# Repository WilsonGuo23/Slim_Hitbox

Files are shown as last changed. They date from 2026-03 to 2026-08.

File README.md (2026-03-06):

# Slim Hitbox Enclosure

This repository contains 3D models, assembly instructions, and detailed documentation for building a compact, 3D-printed hitbox-style arcade controller.

## Project Overview

This Slim Hitbox Enclosure provides a slim, portable alternative to traditional arcade controllers, making it ideal for travel and easy setup. It supports 3D printing, simple assembly, and an ergonomic design. 

> **Note**: Version 1 is exclusively in the southpaw (left-handed) layout. Currently, there is no orthodox (right-handed) version.

## Features

- **Compact and Slim Design**: A low-profile layout optimized for easy handling and storage.
- **3D Printable Components**: Fully printable in standard PLA/ABS materials.
- **Ergonomic Design**: Includes a wrist rest for comfort.
- **Comfortable Assembly**: Chamfered screw holes provide a smoother finish.

## Attributions

This project uses GP2040 to enable the microcontroller to function as a game controller. Special thanks to the knowledgeable members of the GP2040 Discord community for their assistance and expertise, and to the helpful contributors on the r/pcb subreddit for reviewing the board's usability before it was sent for production.

## Prerequisites

- Access to a 3D printer and filament (PLA, ABS, or similar recommended)
- Personal Computer with USB port
- Soldering equipment and basic assembly tools

## Instructions

1. **PCB Manufacturing**: Have the PCB manufactured using the Gerber files in the `fab` folder.
2. **Download STL Files**: Access the STL files from the `models` directory.
3. **Slice and Print**: Use slicing software like Cura or PrusaSlicer to prepare and print the models. Adjust settings as needed based on your specific printer and filament.
4. **Assemble**: Follow the assembly instructions below.

## Parts List

- **Buttons**: 9x 30mm buttons, 3x 24mm buttons
- **Keycaps**: 5x keycaps
- **Panels**: 1x top panel, 1x bottom panel
- **Cables**: 1x Micro USB male to USB male cable ([link](https://www.amazon.com/gp/product/B08BZD66H4/ref=ppx_yo_dt_b_search_asin_title?ie=UTF8&psc=1)) 1x, 1x USB female to USB male cable
  1. (length should match your preferred distance to console or PC)
- **Hardware**: 6x M3 x 20mm screws, 6x M3 bolts
- **Feet**: 6x printed feet
  1. (ensure bolts fit snugly)
- **Electrical Components**:
  - 1x Raspberry Pi Pico
  - 17x MX Cherry or MX Cherry-compatible keyswitches
  - 2 rows of 100-pin male header pins ([link](https://www.amazon.com/dp/B06ZZN8L9S?ref=ppx_yo2ov_dt_b_fed_asin_title))
  - 1x PCB

## Assembly Instructions

1. **Prepare Feet**: Apply a strong bonding agent to the inner walls of each foot, then insert bolts into all six printed feet.
2. **Microcontroller Setup**: Solder male header pins to the Pico microcontroller.
3. **PCB Assembly**: Solder the microcontroller to the PCB using the header pins.
4. **Keyswitch Installation**: Solder all 17 keyswitches onto the PCB.
5. **Cable Guide**: Attach the Micro USB to USB cable to the Pico and guide it through the channels in the top panel.
6. **Enclosure Assembly**: Place the PCB between the top and bottom panels.
7. **Secure Panels**: Screw the panels together and attach them with the feet.
8. **Install Buttons**: Attach all printed buttons, following the image shown below.

   Slim Hitbox Assembled

9. **Attach USB Cable**: Connect the USB female-to-male cable to the exposed USB head.

## Configuration

1. **Download Firmware**: Get the appropriate microcontroller `.uf2` file from the [GP2040 website](https://gp2040-ce.info/downloads/).
2. **Connect and Install Firmware**: Plug the USB cable into a PC, then drag the `.uf2` file into the storage device that appears in the file explorer when the hitbox is connected.
3. **Configuration Setup**: If the default layout is unsatisfactory, use the [web configurator](https://gp2040-ce.info/web-configurator/) to customize the button layout.
4. **Ready to Play**: Boot up your favorite fighting game and enjoy!

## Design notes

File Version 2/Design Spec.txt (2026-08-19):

# Modular Arcade Controller PCBs

## Project Specification

**Version:** 0.1 Draft

---

# 1. Purpose

The Modular Arcade Controller PCBs project is an open-source collection of PCBs designed to simplify the construction of custom arcade controllers. The project divides common controller functions into dedicated, reusable modules that reduce wiring complexity and improve maintainability.

---

# 2. Motivation

Custom arcade controllers often require extensive point-to-point wiring, making assembly, modification, and troubleshooting time-consuming.

This project replaces much of that wiring with standardized PCB modules that can be reused across multiple controller builds.

---

# 3. Scope

This document defines the overall architecture of the Modular Arcade Controller PCBs project.

Detailed electrical, mechanical, and functional requirements for each PCB are defined in their respective specification documents.

---

# 4. Objectives

The project shall:

* Reduce controller assembly time.
* Minimize custom wiring.
* Support modular hardware expansion.
* Be reusable across multiple controller designs.
* Remain compatible with GP2040-CE.
* Be suitable for hobbyist assembly.

---

# 5. System Architecture

The project consists of four primary PCB modules:

* Action Button PCB
* Movement Button PCB
* Administrative Button PCB
* OLED Display PCB

The Action Button PCB serves as the central controller while the remaining modules provide dedicated functionality through standardized interfaces.

---

# 6. Design Principles

All modules should:

* Perform a single primary function.
* Use standardized electrical interfaces.
* Be reusable across controller designs.
* Be easy to manufacture and assemble.
* Maintain compatibility with future project revisions.

---

# 7. Action Button PCB

The Action Button PCB serves as the primary controller for the system.

It hosts a Raspberry Pi Pico running GP2040-CE firmware while interfacing with the controller's primary action buttons. It also provides power and communication interfaces for the remaining modules.

---

# 8. Movement Button PCB

The Movement Button PCB provides directional inputs for the controller.

It interfaces with the Action Button PCB through the project's standardized connector interface.

---

# 9. Administrative Button PCB

The Administrative Button PCB provides non-gameplay controller inputs such as Start, Select, Home/Xbox, and other system buttons supported by GP2040-CE.

It communicates with the Action Button PCB using the project's standardized interface.

---

# 10. OLED Display PCB

The OLED Display PCB provides the controller's user interface.

It supports an OLED display and a rotary encoder used for menu navigation and firmware-supported configuration features.

---

# 11. Module Interfaces

All PCB modules shall connect using standardized electrical interfaces.

Interface specifications, connector pinouts, and communication protocols are defined separately to ensure compatibility between hardware revisions.

---

# 12. Firmware

The system is designed for GP2040-CE running on the Raspberry Pi Pico located on the Action Button PCB.

Additional modules shall integrate using interfaces supported by the firmware whenever practical.

---

# 13. Future Development

Additional PCB modules may be developed to extend the functionality of the controller.

Future modules should follow the architectural principles defined in this specification and maintain compatibility with the existing module interfaces.

PCB Through holes should be 3mm from each side and pushbutton switch centers should be 24mm from the closest side. 
LEDs are to be placed above the switch 11mm from center to center
Resistors that pair with the LED should be placed to the right of the LED with 4mm from through hole to through hole

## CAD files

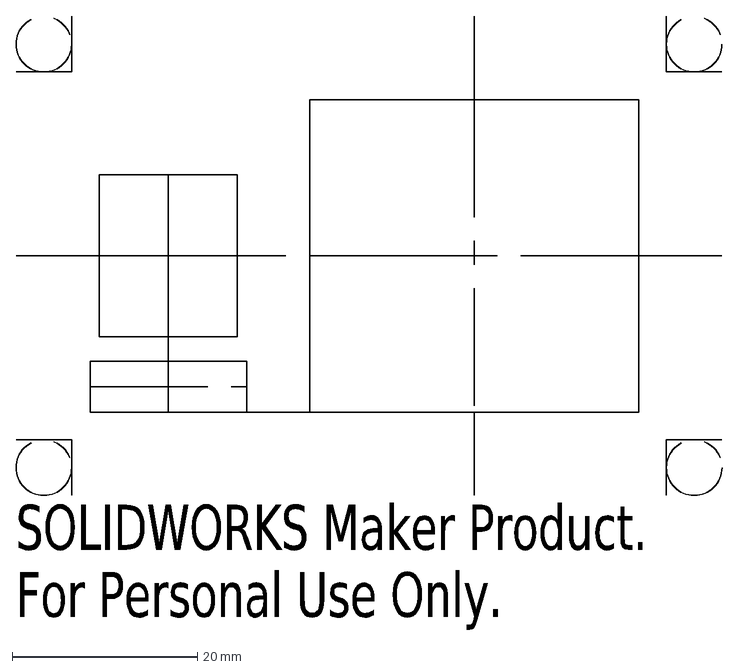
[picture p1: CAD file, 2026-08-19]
Version 2/Solidworks Sketch References/OLED_Display_PCB_User_Sketch_Reference.DXF
SOLIDWORKS Maker Product.
For Personal Use Only.

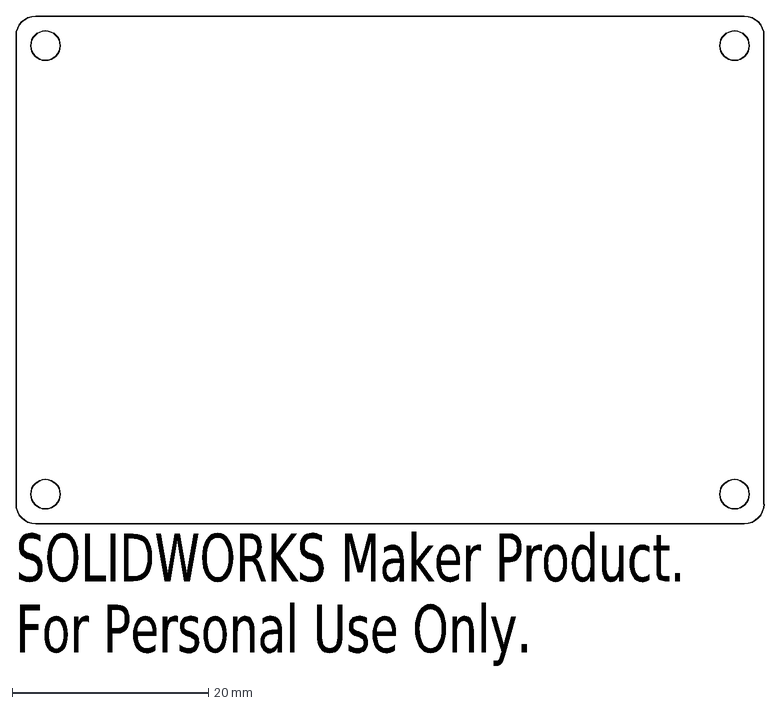
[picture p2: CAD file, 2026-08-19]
Version 2/Solidworks Sketch References/OLED_Display_PCB_Edge_Cuts_Reference.DXF
SOLIDWORKS Maker Product.
For Personal Use Only.

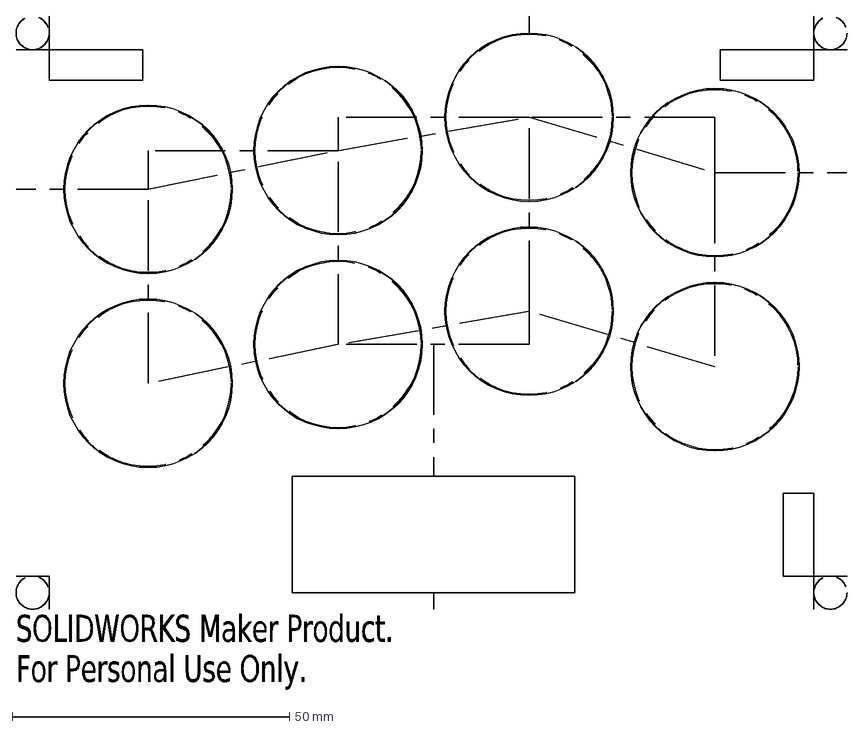
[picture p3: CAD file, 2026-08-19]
Version 2/Solidworks Sketch References/Action_Button_PCB_User_Sketch_Reference.DXF
SOLIDWORKS Maker Product.
For Personal Use Only.

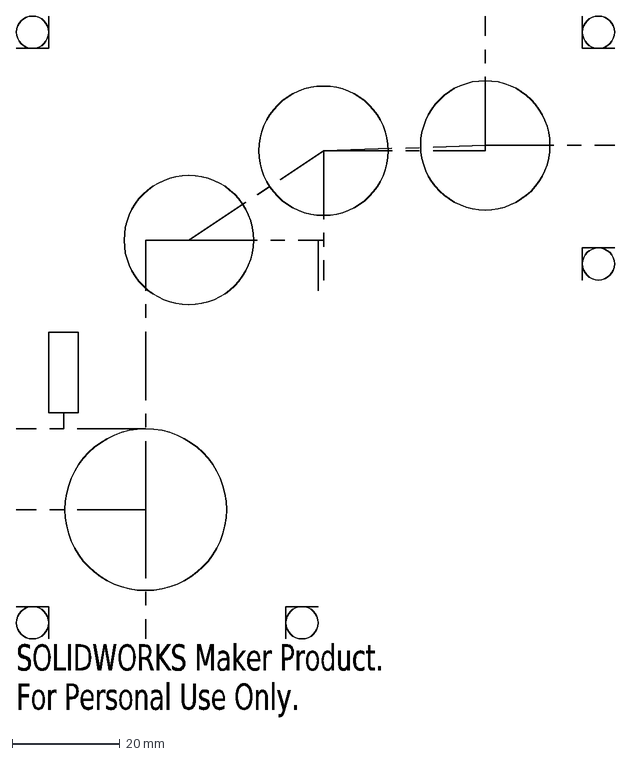
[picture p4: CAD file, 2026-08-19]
Version 2/Solidworks Sketch References/Movement_Button_PCB_User_Sketch_Reference.DXF
SOLIDWORKS Maker Product.
For Personal Use Only.

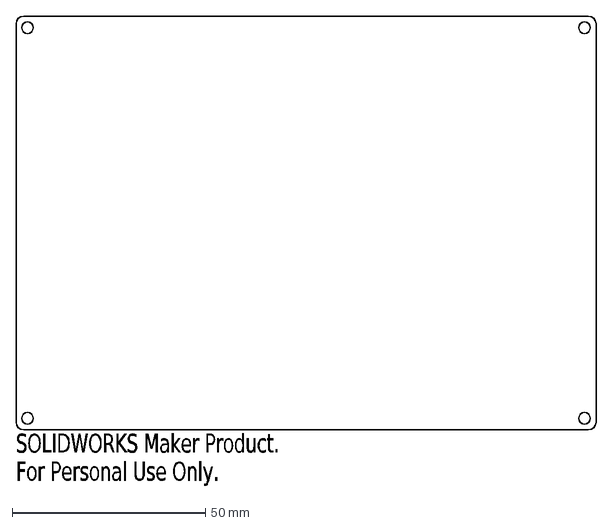
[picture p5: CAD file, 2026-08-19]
Version 2/Solidworks Sketch References/Action_Button_PCB_Edge_Cuts_Reference.DXF
SOLIDWORKS Maker Product.
For Personal Use Only.

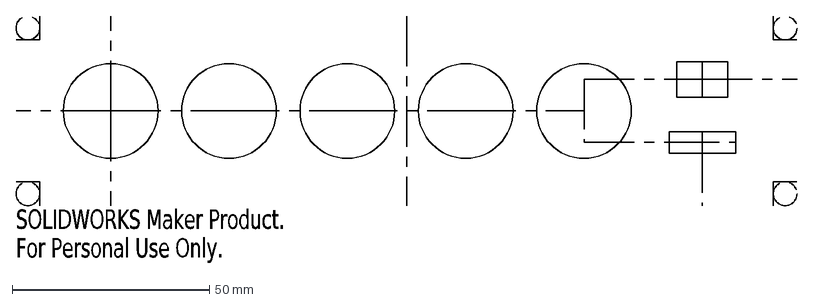
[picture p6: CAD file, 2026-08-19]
Version 2/Solidworks Sketch References/Administrative_PCB_User_Sketch_Reference.DXF
SOLIDWORKS Maker Product.
For Personal Use Only.

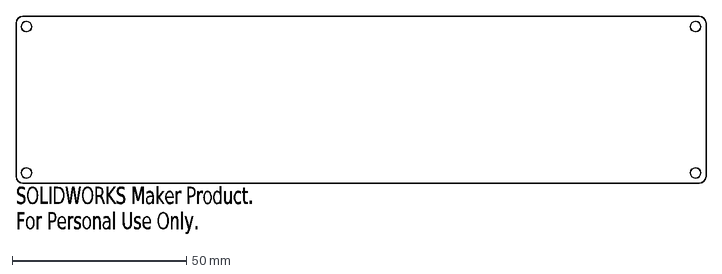
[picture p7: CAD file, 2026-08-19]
Version 2/Solidworks Sketch References/Movement_Button_PCB_Edge_Cuts_Reference.DXF
SOLIDWORKS Maker Product.
For Personal Use Only.

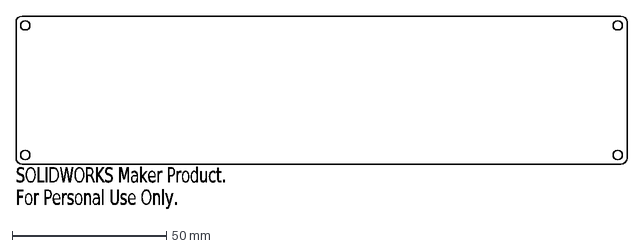
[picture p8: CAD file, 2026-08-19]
Version 2/Solidworks Sketch References/Administrative_PCB_Edge_Cuts_Reference.DXF
SOLIDWORKS Maker Product.
For Personal Use Only.

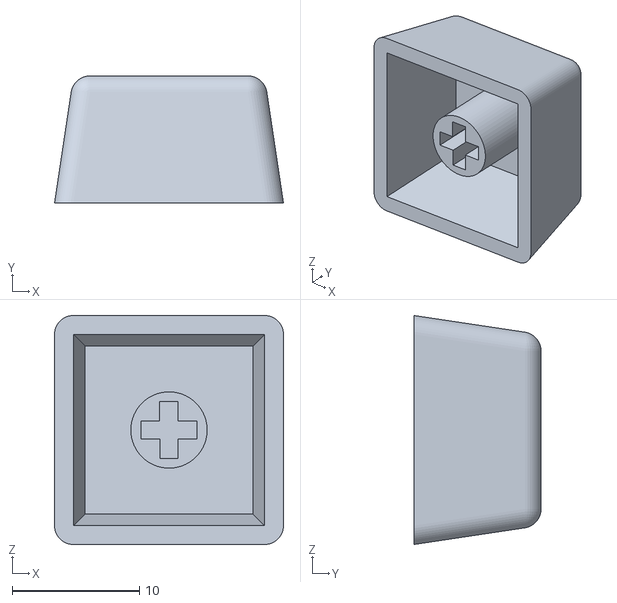
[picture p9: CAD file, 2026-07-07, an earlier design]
Version 1/keycap.stl
18.0 x 10.0 x 18.0

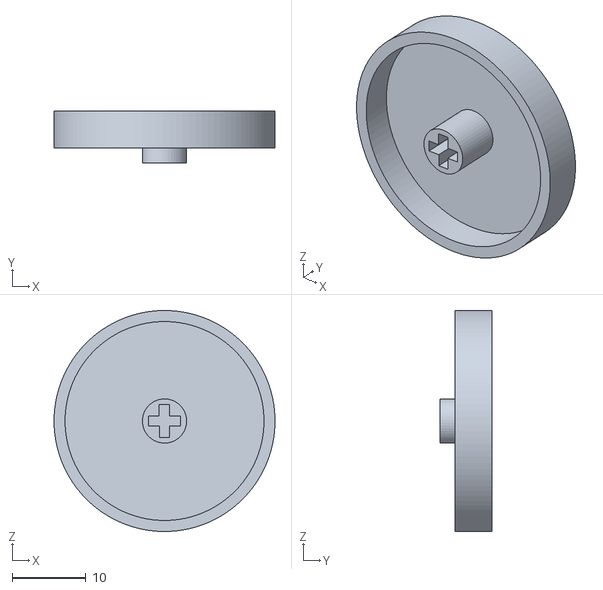
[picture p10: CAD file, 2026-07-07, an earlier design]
Version 1/30mm button.stl
30.0 x 7.00 x 30.0

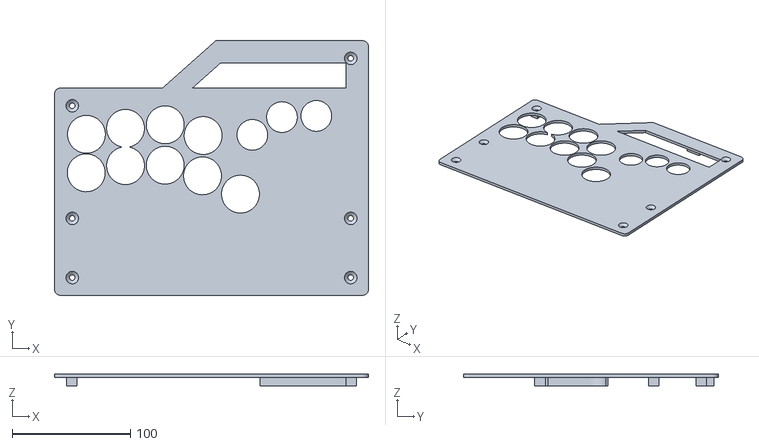
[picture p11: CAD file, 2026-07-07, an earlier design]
Version 1/slim top.stl
265.0 x 215.0 x 10.0

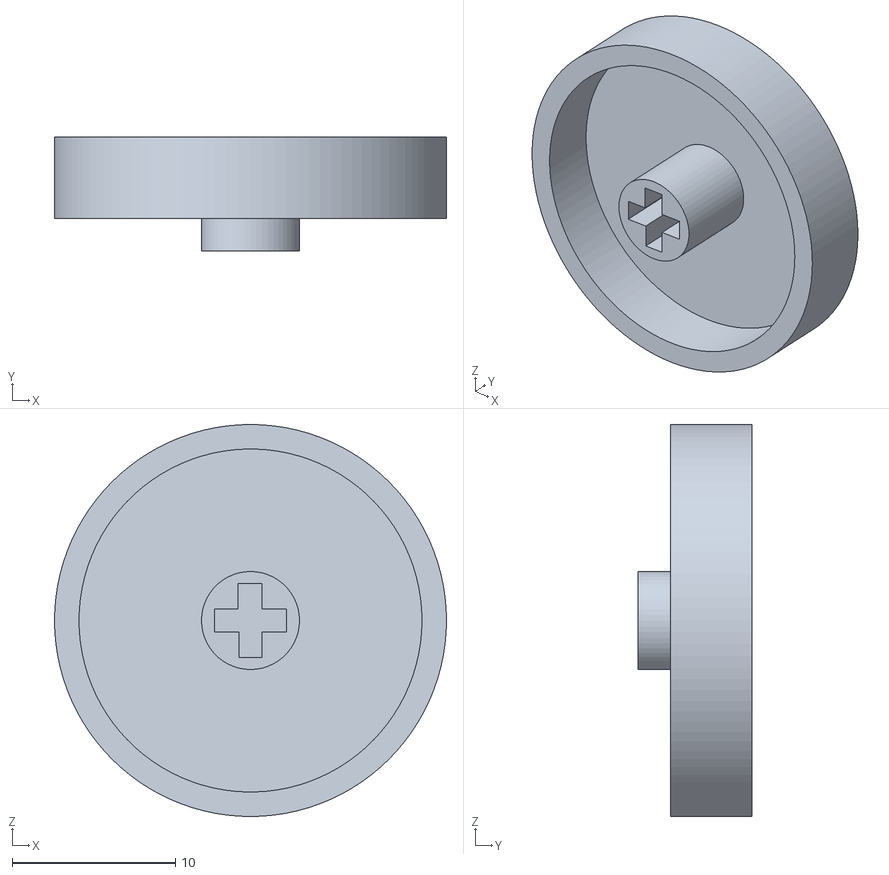
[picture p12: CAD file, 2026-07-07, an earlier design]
Version 1/24mm button.stl
24.0 x 7.00 x 24.0

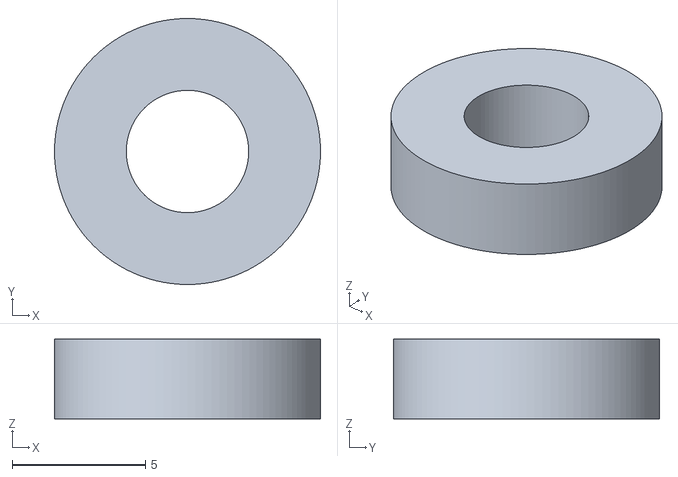
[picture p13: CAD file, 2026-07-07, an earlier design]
Version 1/hole test.stl
10.0 x 10.0 x 3.00

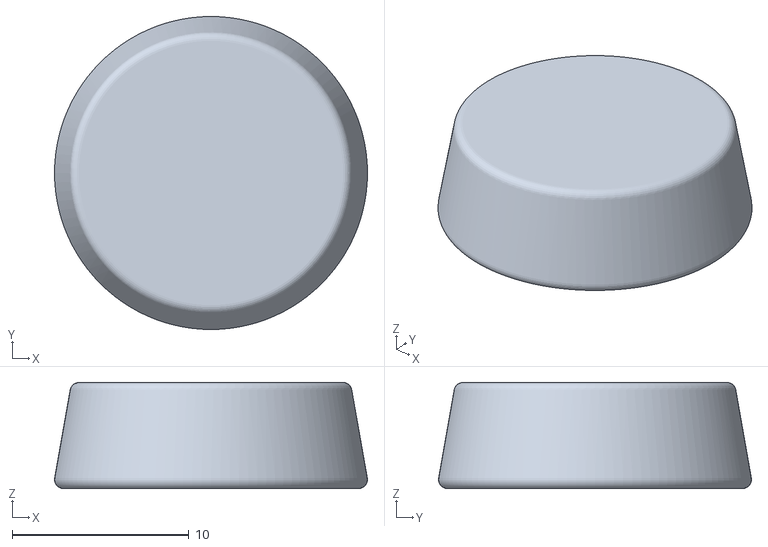
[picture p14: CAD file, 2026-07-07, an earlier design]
Version 1/foot.stl
17.7 x 17.7 x 6.00

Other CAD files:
Version 2/OLED_Display_PCB_Reference.SLDPRT
Version 2/Action_Button_PCB_Reference.SLDPRT
Version 2/Movement_Button_PCB_Reference.SLDPRT
Version 2/Administrative_PCB_Reference.SLDPRT
Version 1/slim_bottom.stl

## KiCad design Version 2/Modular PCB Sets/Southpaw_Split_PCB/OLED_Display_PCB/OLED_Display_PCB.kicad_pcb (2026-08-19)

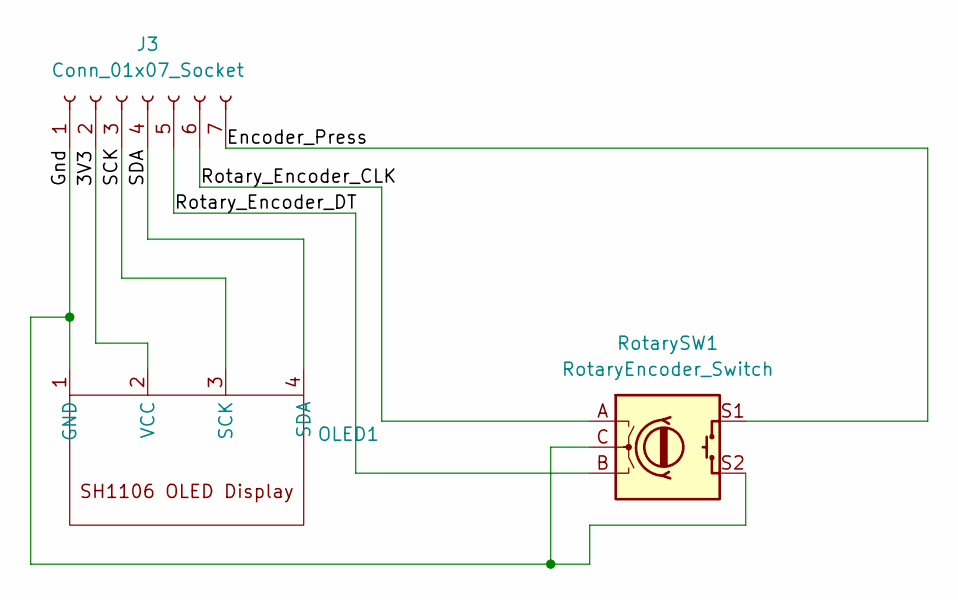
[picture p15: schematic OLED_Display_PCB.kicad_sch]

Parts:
J3: Conn_01x07_Socket; JST_PH_B7B-PH-K_1x07_P2.00mm_Vertical
OLED1: Hosyond SH1106 OLED Display
RotarySW1: RotaryEncoder_Switch; RotaryEncoder_Alps_EC11E-Switch_Vertical_H20mm

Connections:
/3V3: J3.2, OLED1.2 (VCC)
/Encoder_Press: J3.7, RotarySW1.S1
/Gnd: J3.1, OLED1.1 (GND), RotarySW1.C, RotarySW1.S2
/Rotary_Encoder_CLK: J3.6, RotarySW1.A
/Rotary_Encoder_DT: J3.5, RotarySW1.B
/SCK: J3.3, OLED1.3 (SCK)
/SDA: J3.4, OLED1.4 (SDA)

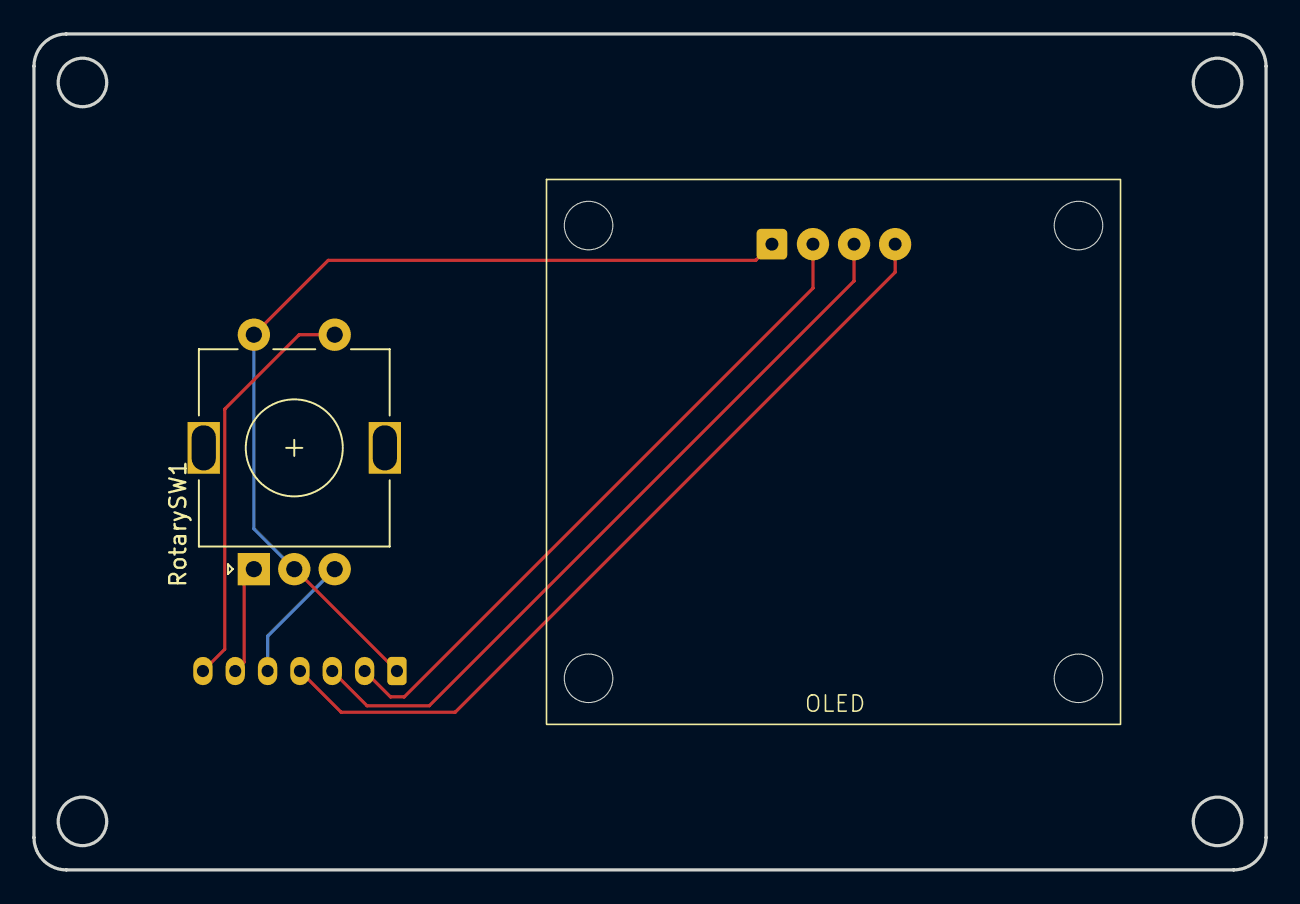
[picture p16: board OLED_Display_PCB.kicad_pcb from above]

Board: 2 copper layers, 76.2 x 51.7 mm, 3 parts (1 on the bottom side), 7 nets.

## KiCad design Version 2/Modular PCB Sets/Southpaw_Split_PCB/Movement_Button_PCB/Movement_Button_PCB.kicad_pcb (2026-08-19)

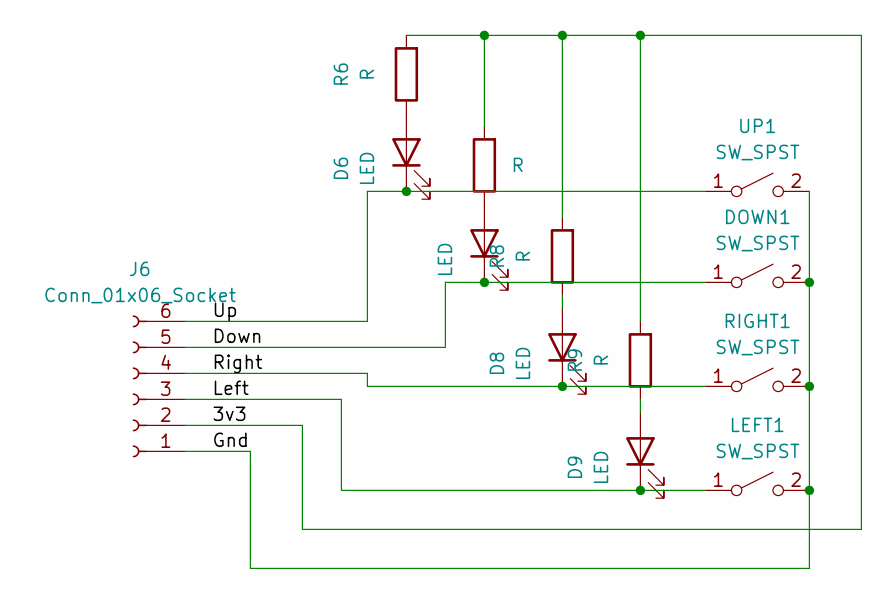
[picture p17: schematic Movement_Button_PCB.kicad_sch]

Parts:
D6, D7, D8, D9: LED; LED_D5.0mm
DOWN1: SW_SPST; SW_Cherry_MX_1.00u_PCB
J6: Conn_01x06_Socket; JST_PH_B6B-PH-K_1x06_P2.00mm_Vertical
LEFT1: SW_SPST; SW_Cherry_MX_1.00u_PCB
R6, R7, R8, R9: R; R_Axial_DIN0207_L6.3mm_D2.5mm_P10.16mm_Horizontal
RIGHT1: SW_SPST; SW_Cherry_MX_1.00u_PCB
UP1: SW_SPST; SW_Cherry_MX_1.00u_PCB

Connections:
/3v3: J6.2, R6.2, R7.2, R8.2, R9.2
/Down: D7.1 (K), DOWN1.1 (A), J6.5
/Gnd: DOWN1.2 (B), J6.1, LEFT1.2 (B), RIGHT1.2 (B), UP1.2 (B)
/Left: D9.1 (K), J6.3, LEFT1.1 (A)
/Right: D8.1 (K), J6.4, RIGHT1.1 (A)
/Up: D6.1 (K), J6.6, UP1.1 (A)
unnamed: D6.2 (A), R6.1
unnamed: D7.2 (A), R7.1
unnamed: D8.2 (A), R8.1
unnamed: D9.2 (A), R9.1

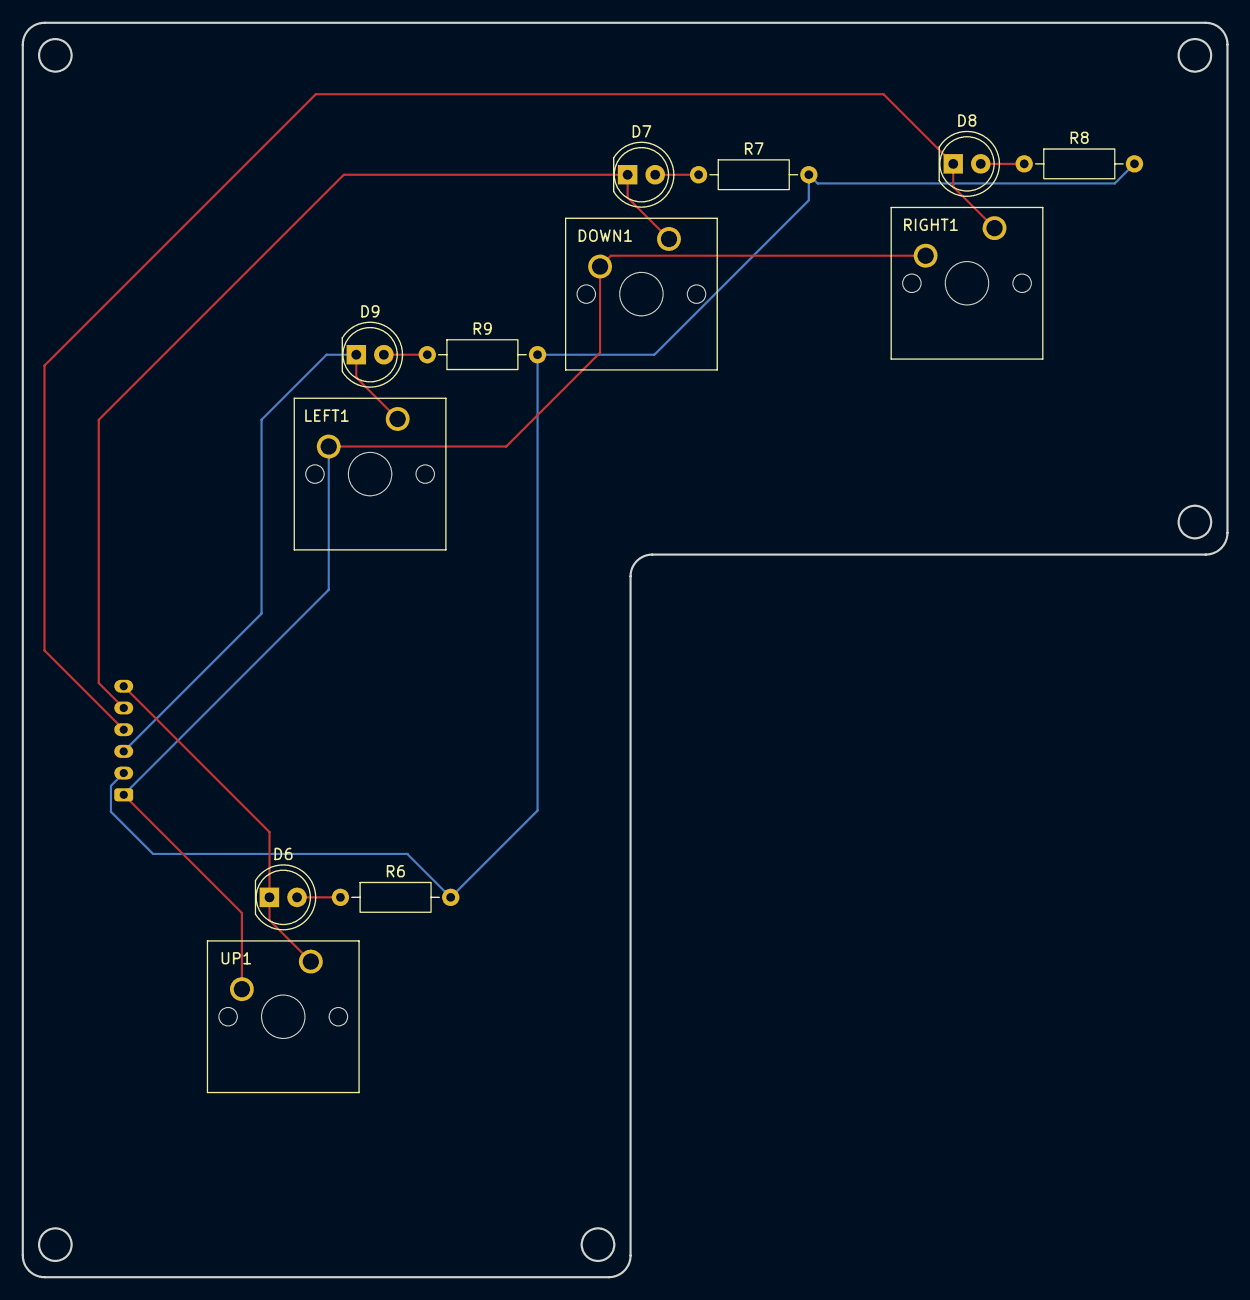
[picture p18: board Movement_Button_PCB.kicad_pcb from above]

Board: 2 copper layers, 111.0 x 115.6 mm, 13 parts (1 on the bottom side), 10 nets.

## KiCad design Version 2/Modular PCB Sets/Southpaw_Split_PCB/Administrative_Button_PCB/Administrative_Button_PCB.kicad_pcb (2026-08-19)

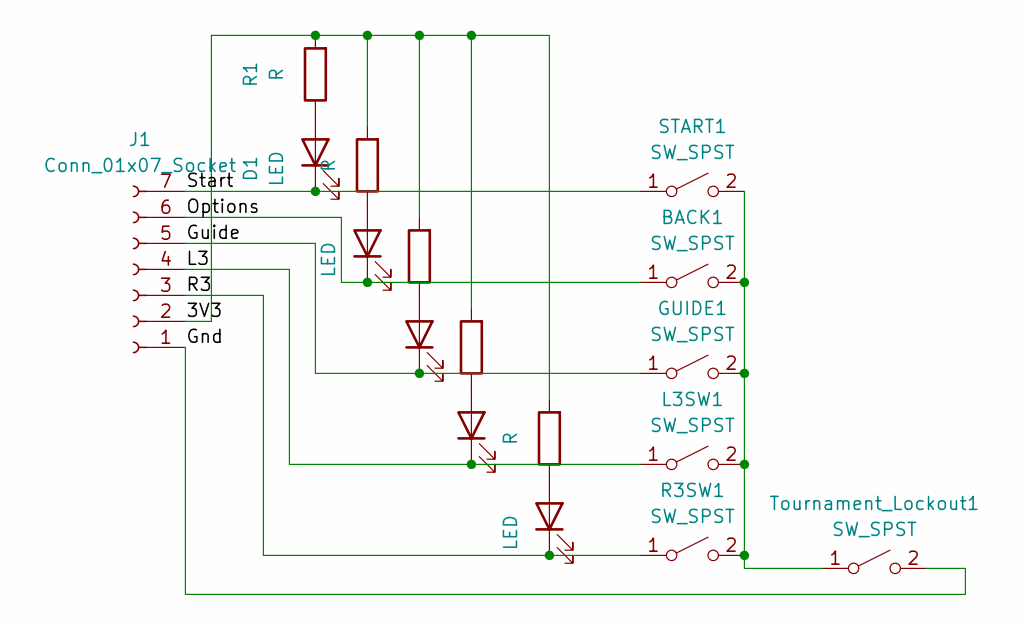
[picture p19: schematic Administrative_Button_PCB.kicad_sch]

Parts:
BACK1: SW_SPST; SW_Cherry_MX_1.00u_PCB
D1, D2, D3, D4, D5: LED; LED_D5.0mm
GUIDE1: SW_SPST; SW_Cherry_MX_1.00u_PCB
J1: Conn_01x07_Socket; JST_PH_B7B-PH-K_1x07_P2.00mm_Vertical
L3SW1: SW_SPST; SW_Cherry_MX_1.00u_PCB
R1, R2, R3, R4, R5: R; R_Axial_DIN0207_L6.3mm_D2.5mm_P10.16mm_Horizontal
R3SW1: SW_SPST; SW_Cherry_MX_1.00u_PCB
START1: SW_SPST; SW_Cherry_MX_1.00u_PCB
Tournament_Lockout1: SW_SPST; MTS-101 Toggle Switch

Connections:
/3V3: J1.2, R1.2, R2.2, R3.2, R4.2, R5.2
/Gnd: J1.1, Tournament_Lockout1.2 (B)
/Guide: D3.1 (K), GUIDE1.1 (A), J1.5
/L3: D4.1 (K), J1.4, L3SW1.1 (A)
/Options: BACK1.1 (A), D2.1 (K), J1.6
/R3: D5.1 (K), J1.3, R3SW1.1 (A)
/Start: D1.1 (K), J1.7, START1.1 (A)
unnamed: BACK1.2 (B), GUIDE1.2 (B), L3SW1.2 (B), R3SW1.2 (B), START1.2 (B), Tournament_Lockout1.1 (A)
unnamed: D1.2 (A), R1.1
unnamed: D2.2 (A), R2.1
unnamed: D3.2 (A), R3.1
unnamed: D4.2 (A), R4.1
unnamed: D5.2 (A), R5.1

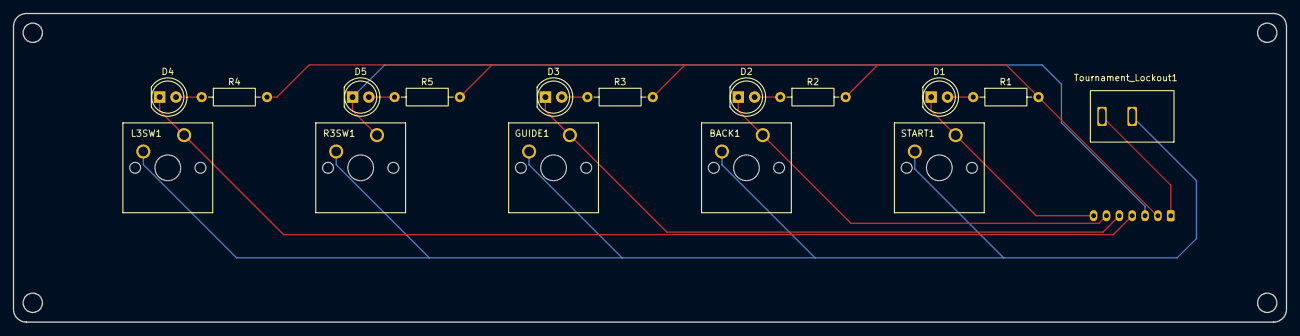
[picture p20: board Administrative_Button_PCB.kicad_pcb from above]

Board: 2 copper layers, 198.0 x 48.0 mm, 17 parts (1 on the bottom side), 13 nets.

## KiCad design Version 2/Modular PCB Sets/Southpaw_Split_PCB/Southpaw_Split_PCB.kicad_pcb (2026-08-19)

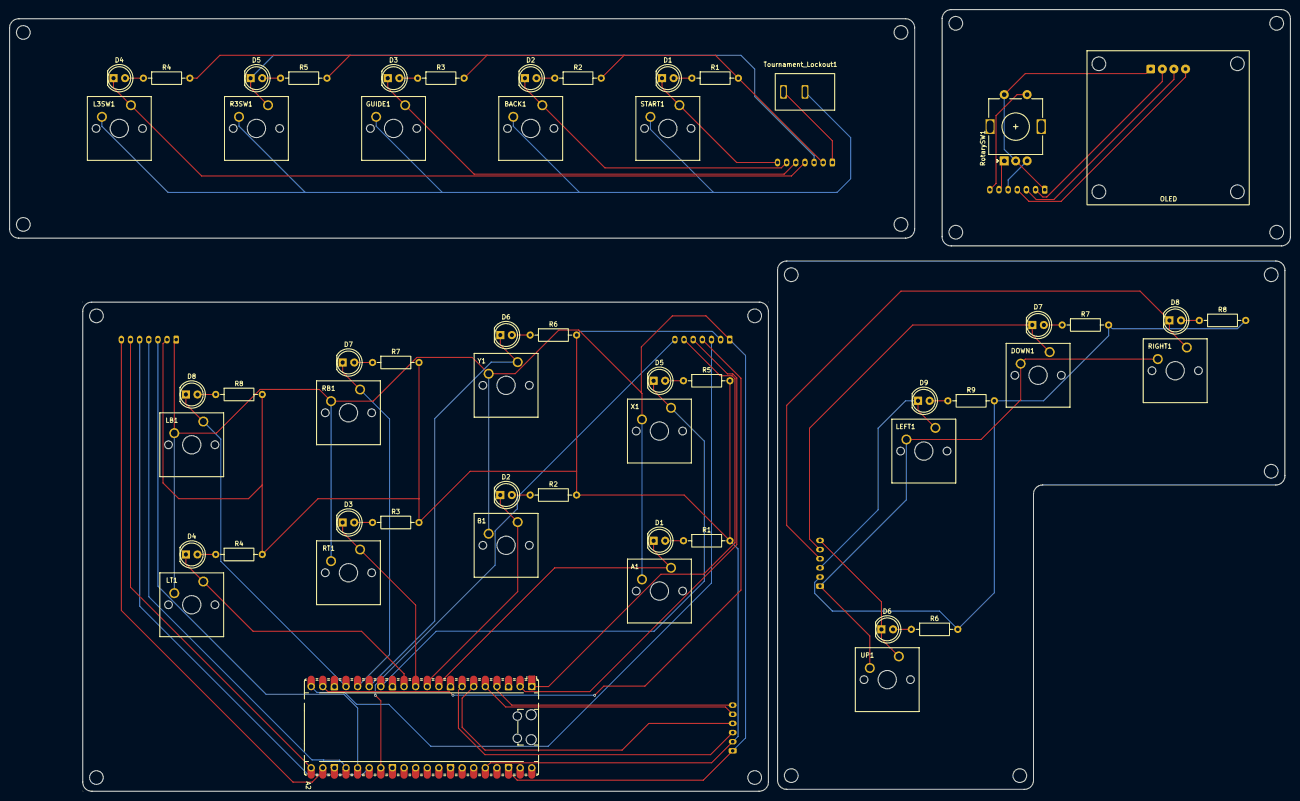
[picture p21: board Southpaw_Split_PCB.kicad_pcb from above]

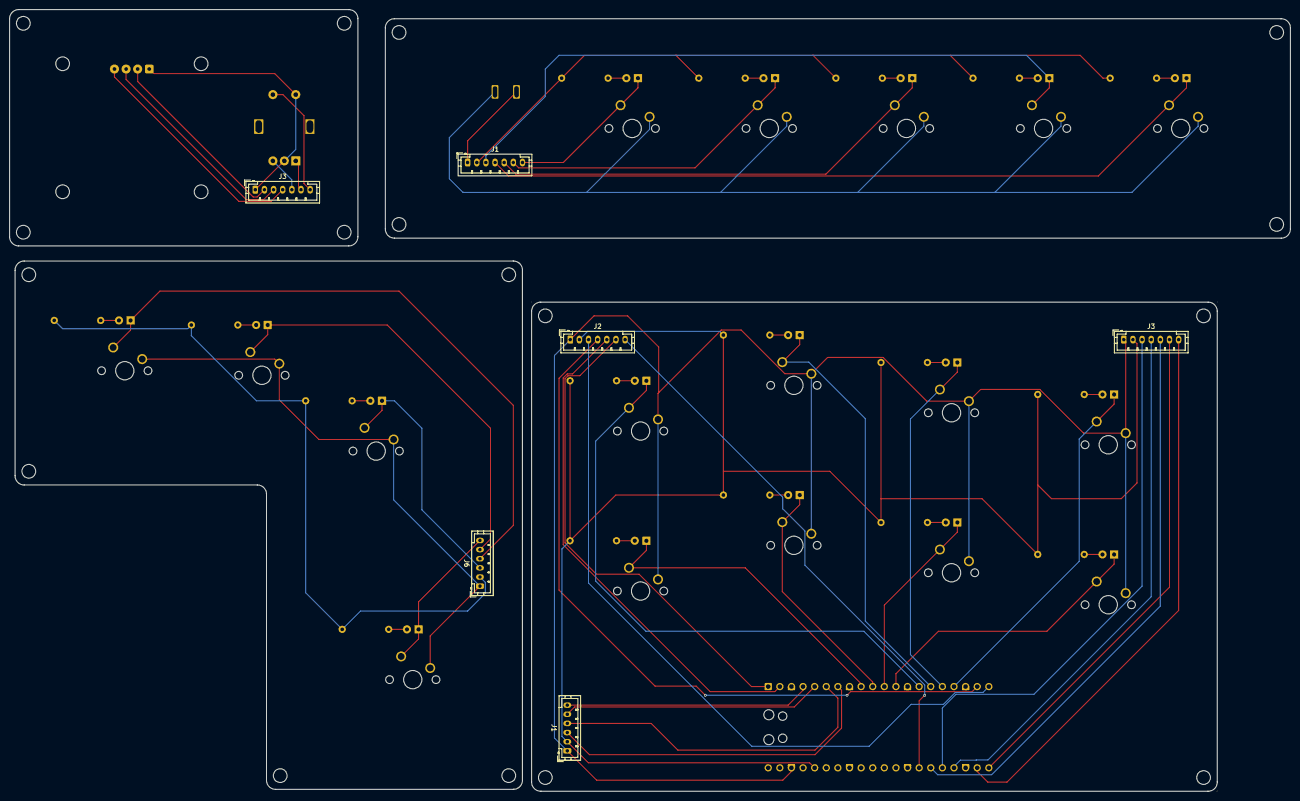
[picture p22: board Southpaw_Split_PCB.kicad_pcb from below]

Board: 2 copper layers, 280.2 x 171.0 mm, 61 parts (6 on the bottom side), 37 nets.

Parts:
A1: SW_SPST; SW_Cherry_MX_1.00u_PCB
A2: RaspberryPi_Pico; RaspberryPi_Pico_Common_Unspecified
B1: SW_SPST; SW_Cherry_MX_1.00u_PCB
BACK1: SW_SPST; SW_Cherry_MX_1.00u_PCB
D1, D1#2, D2, D2#2, D3, D3#2, D4, D4#2, D5, D5#2, D6, D6#2, D7, D7#2, D8, D8#2, D9: LED; LED_D5.0mm
DOWN1: SW_SPST; SW_Cherry_MX_1.00u_PCB
GUIDE1: SW_SPST; SW_Cherry_MX_1.00u_PCB
J1, J6: Conn_01x06_Socket; JST_PH_B6B-PH-K_1x06_P2.00mm_Vertical
J1#2, J2, J3, J3#2: Conn_01x07_Socket; JST_PH_B7B-PH-K_1x07_P2.00mm_Vertical
L3SW1: SW_SPST; SW_Cherry_MX_1.00u_PCB
LB1: SW_SPST; SW_Cherry_MX_1.00u_PCB
LEFT1: SW_SPST; SW_Cherry_MX_1.00u_PCB
LT1: SW_SPST; SW_Cherry_MX_1.00u_PCB
OLED1: Hosyond SH1106 OLED Display
R1, R1#2, R2, R2#2, R3, R3#2, R4, R4#2, R5, R5#2, R6, R6#2, R7, R7#2, R8, R8#2, R9: R; R_Axial_DIN0207_L6.3mm_D2.5mm_P10.16mm_Horizontal
R3SW1: SW_SPST; SW_Cherry_MX_1.00u_PCB
RB1: SW_SPST; SW_Cherry_MX_1.00u_PCB
RIGHT1: SW_SPST; SW_Cherry_MX_1.00u_PCB
RT1: SW_SPST; SW_Cherry_MX_1.00u_PCB
RotarySW1: RotaryEncoder_Switch; RotaryEncoder_Alps_EC11E-Switch_Vertical_H20mm
START1: SW_SPST; SW_Cherry_MX_1.00u_PCB
Tournament_Lockout1: SW_SPST; MTS-101 Toggle Switch
UP1: SW_SPST; SW_Cherry_MX_1.00u_PCB
X1: SW_SPST; SW_Cherry_MX_1.00u_PCB
Y1: SW_SPST; SW_Cherry_MX_1.00u_PCB

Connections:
3v3: A2.36 (3V3), J1.2, J2.2, J3#2.2, R1.2, R2#2.2, R3#2.2, R4.2, R5.2, R6#2.2, R7.2, R8.2
/3V3: J1#2.2, J3.2, OLED1.2 (VCC), R1#2.2, R2.2, R3.2, R4#2.2, R5#2.2
/3v3: J6.2, R6.2, R7#2.2, R8#2.2, R9.2
/Down: A2.5 (GPIO3), D7.1 (K), DOWN1.1 (A), J1.5, J6.5
/Encoder_Press: A2.27 (GPIO21), J2.7, J3.7, RotarySW1.S1
/Gnd: DOWN1.2 (B), J1#2.1, J3.1, J6.1, LEFT1.2 (B), OLED1.1 (GND), RIGHT1.2 (B), RotarySW1.C, RotarySW1.S2, Tournament_Lockout1.2 (B), UP1.2 (B)
/Guide: A2.26 (GPIO20), D3#2.1 (K), GUIDE1.1 (A), J1#2.5, J3#2.5
/L3: A2.24 (GPIO18), D4#2.1 (K), J1#2.4, J3#2.4, L3SW1.1 (A)
/Left: A2.7 (GPIO5), D9.1 (K), J1.3, J6.3, LEFT1.1 (A)
/Options: A2.21 (GPIO16), BACK1.1 (A), D2#2.1 (K), J1#2.6, J3#2.6
/R3: A2.25 (GPIO19), D5#2.1 (K), J1#2.3, J3#2.3, R3SW1.1 (A)
/Right: A2.6 (GPIO4), D8.1 (K), J1.4, J6.4, RIGHT1.1 (A)
/Rotary_Encoder_CLK: A2.1 (GPIO0), J2.6, J3.6, RotarySW1.A
/Rotary_Encoder_DT: A2.2 (GPIO1), J2.5, J3.5, RotarySW1.B
/SCK: A2.20 (GPIO15), J2.3, J3.3, OLED1.3 (SCK)
/SDA: A2.19 (GPIO14), J2.4, J3.4, OLED1.4 (SDA)
/Start: A2.22 (GPIO17), D1.1 (K), J1#2.7, J3#2.7, START1.1 (A)
/Up: A2.4 (GPIO2), D6.1 (K), J1.6, J6.6, UP1.1 (A)
A: A1.1 (A), A2.9 (GPIO6), D1#2.1 (K)
B: A2.10 (GPIO7), B1.1 (A), D2.1 (K)
GND: A1.2 (B), A2.3 (GND), A2.8 (GND), A2.13 (GND), A2.18 (GND), A2.23 (GND), A2.28 (GND), A2.38 (GND), B1.2 (B), J1.1, J2.1, J3#2.1, LB1.2 (B), LT1.2 (B), RB1.2 (B), RT1.2 (B), X1.2 (B), Y1.2 (B)
LB: A2.17 (GPIO13), D8#2.1 (K), LB1.1 (A)
LT: A2.12 (GPIO9), D4.1 (K), LT1.1 (A)
unnamed: BACK1.2 (B), GUIDE1.2 (B), L3SW1.2 (B), R3SW1.2 (B), START1.2 (B), Tournament_Lockout1.1 (A)
unnamed: D1.2 (A), D1#2.2 (A), R1.1, R1#2.1
unnamed: D2.2 (A), D2#2.2 (A), R2.1, R2#2.1
unnamed: D3.2 (A), D3#2.2 (A), R3.1, R3#2.1
unnamed: D4.2 (A), D4#2.2 (A), R4.1, R4#2.1
unnamed: D5.2 (A), D5#2.2 (A), R5.1, R5#2.1
unnamed: D6.2 (A), D6#2.2 (A), R6.1, R6#2.1
unnamed: D7.2 (A), D7#2.2 (A), R7.1, R7#2.1
unnamed: D8.2 (A), D8#2.2 (A), R8.1, R8#2.1
unnamed: D9.2 (A), R9.1
RB: A2.16 (GPIO12), D7#2.1 (K), RB1.1 (A)
RT: A2.11 (GPIO8), D3.1 (K), RT1.1 (A)
X: A2.14 (GPIO10), D5.1 (K), X1.1 (A)
Y: A2.15 (GPIO11), D6#2.1 (K), Y1.1 (A)

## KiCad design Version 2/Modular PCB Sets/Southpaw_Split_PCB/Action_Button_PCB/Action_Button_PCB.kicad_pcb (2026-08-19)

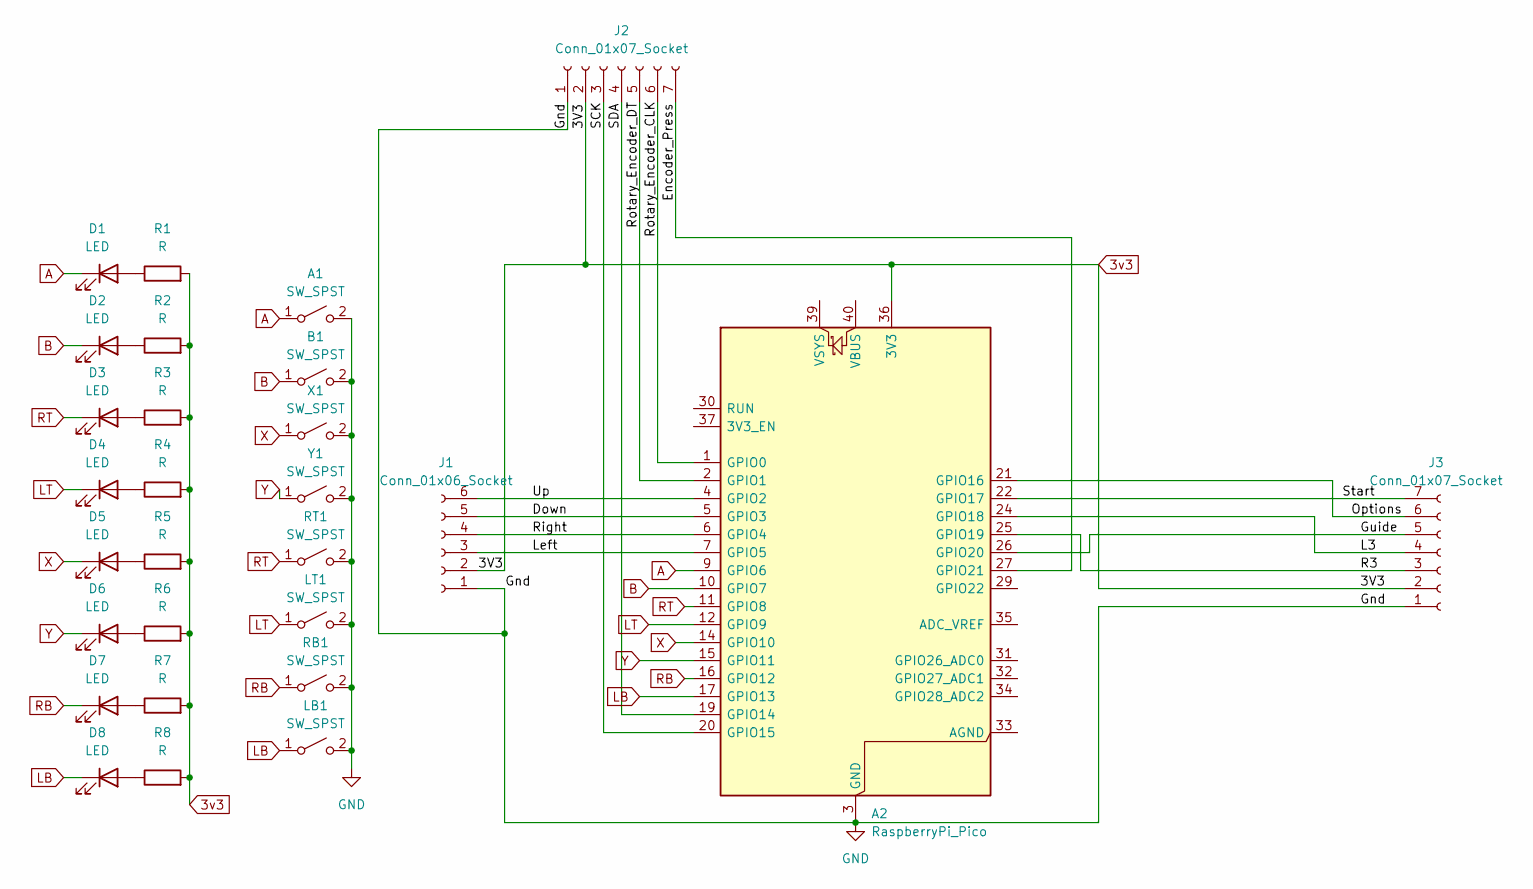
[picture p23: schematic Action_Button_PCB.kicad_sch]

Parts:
A1: SW_SPST; SW_Cherry_MX_1.00u_PCB
A2: RaspberryPi_Pico; RaspberryPi_Pico_Common_Unspecified
B1: SW_SPST; SW_Cherry_MX_1.00u_PCB
D1, D2, D3, D4, D5, D6, D7, D8: LED; LED_D5.0mm
J1: Conn_01x06_Socket; JST_PH_B6B-PH-K_1x06_P2.00mm_Vertical
J2, J3: Conn_01x07_Socket; JST_PH_B7B-PH-K_1x07_P2.00mm_Vertical
LB1: SW_SPST; SW_Cherry_MX_1.00u_PCB
LT1: SW_SPST; SW_Cherry_MX_1.00u_PCB
R1, R2, R3, R4, R5, R6, R7, R8: R; R_Axial_DIN0207_L6.3mm_D2.5mm_P10.16mm_Horizontal
RB1: SW_SPST; SW_Cherry_MX_1.00u_PCB
RT1: SW_SPST; SW_Cherry_MX_1.00u_PCB
X1: SW_SPST; SW_Cherry_MX_1.00u_PCB
Y1: SW_SPST; SW_Cherry_MX_1.00u_PCB

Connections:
3v3: A2.36 (3V3), J1.2, J2.2, J3.2, R1.2, R2.2, R3.2, R4.2, R5.2, R6.2, R7.2, R8.2
/Down: A2.5 (GPIO3), J1.5
/Encoder_Press: A2.27 (GPIO21), J2.7
/Guide: A2.26 (GPIO20), J3.5
/L3: A2.24 (GPIO18), J3.4
/Left: A2.7 (GPIO5), J1.3
/Options: A2.21 (GPIO16), J3.6
/R3: A2.25 (GPIO19), J3.3
/Right: A2.6 (GPIO4), J1.4
/Rotary_Encoder_CLK: A2.1 (GPIO0), J2.6
/Rotary_Encoder_DT: A2.2 (GPIO1), J2.5
/SCK: A2.20 (GPIO15), J2.3
/SDA: A2.19 (GPIO14), J2.4
/Start: A2.22 (GPIO17), J3.7
/Up: A2.4 (GPIO2), J1.6
A: A1.1 (A), A2.9 (GPIO6), D1.1 (K)
B: A2.10 (GPIO7), B1.1 (A), D2.1 (K)
GND: A1.2 (B), A2.3 (GND), A2.8 (GND), A2.13 (GND), A2.18 (GND), A2.23 (GND), A2.28 (GND), A2.38 (GND), B1.2 (B), J1.1, J2.1, J3.1, LB1.2 (B), LT1.2 (B), RB1.2 (B), RT1.2 (B), X1.2 (B), Y1.2 (B)
LB: A2.17 (GPIO13), D8.1 (K), LB1.1 (A)
LT: A2.12 (GPIO9), D4.1 (K), LT1.1 (A)
unnamed: D1.2 (A), R1.1
unnamed: D2.2 (A), R2.1
unnamed: D3.2 (A), R3.1
unnamed: D4.2 (A), R4.1
unnamed: D5.2 (A), R5.1
unnamed: D6.2 (A), R6.1
unnamed: D7.2 (A), R7.1
unnamed: D8.2 (A), R8.1
RB: A2.16 (GPIO12), D7.1 (K), RB1.1 (A)
RT: A2.11 (GPIO8), D3.1 (K), RT1.1 (A)
X: A2.14 (GPIO10), D5.1 (K), X1.1 (A)
Y: A2.15 (GPIO11), D6.1 (K), Y1.1 (A)

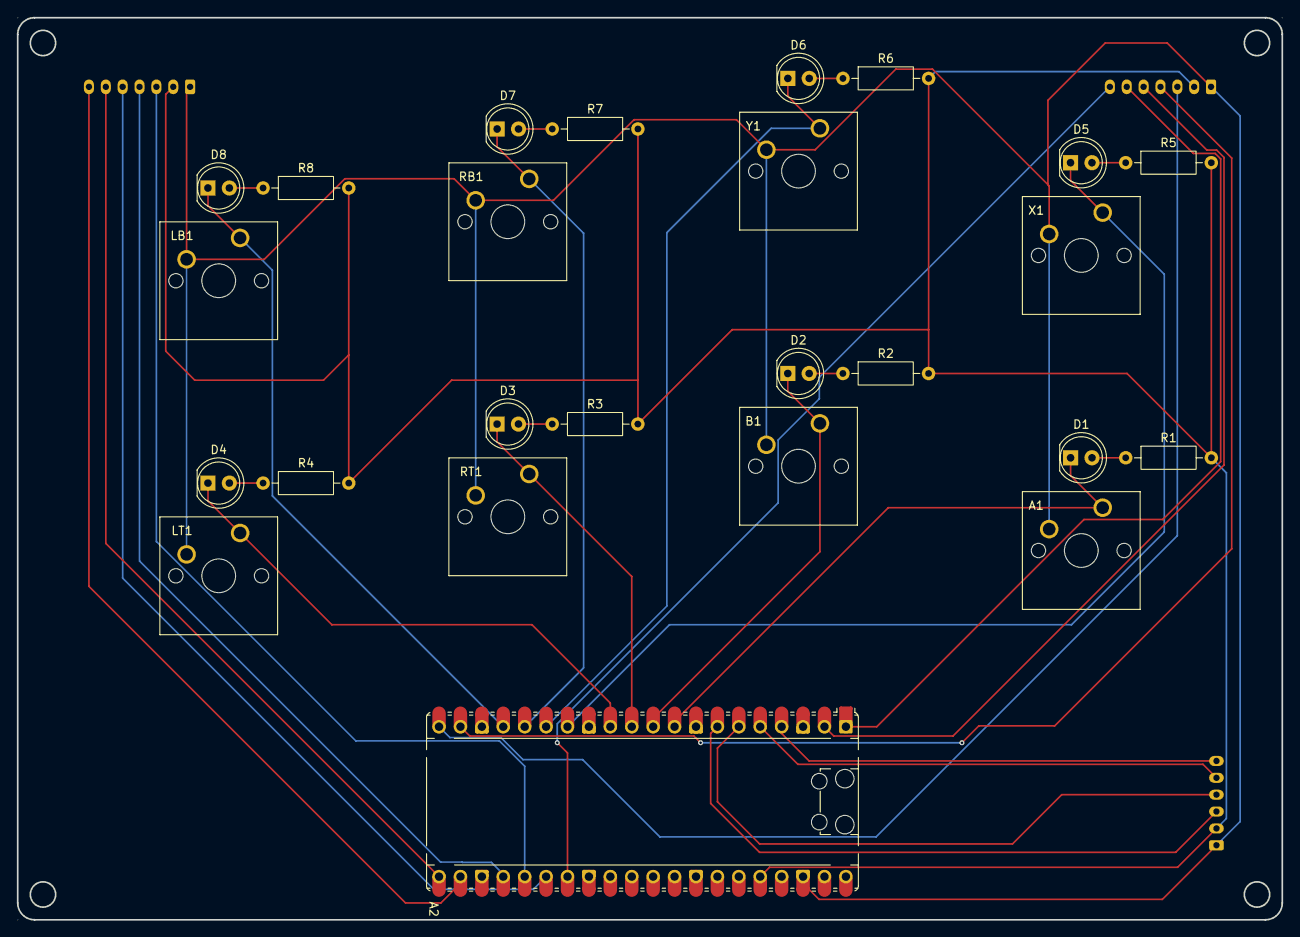
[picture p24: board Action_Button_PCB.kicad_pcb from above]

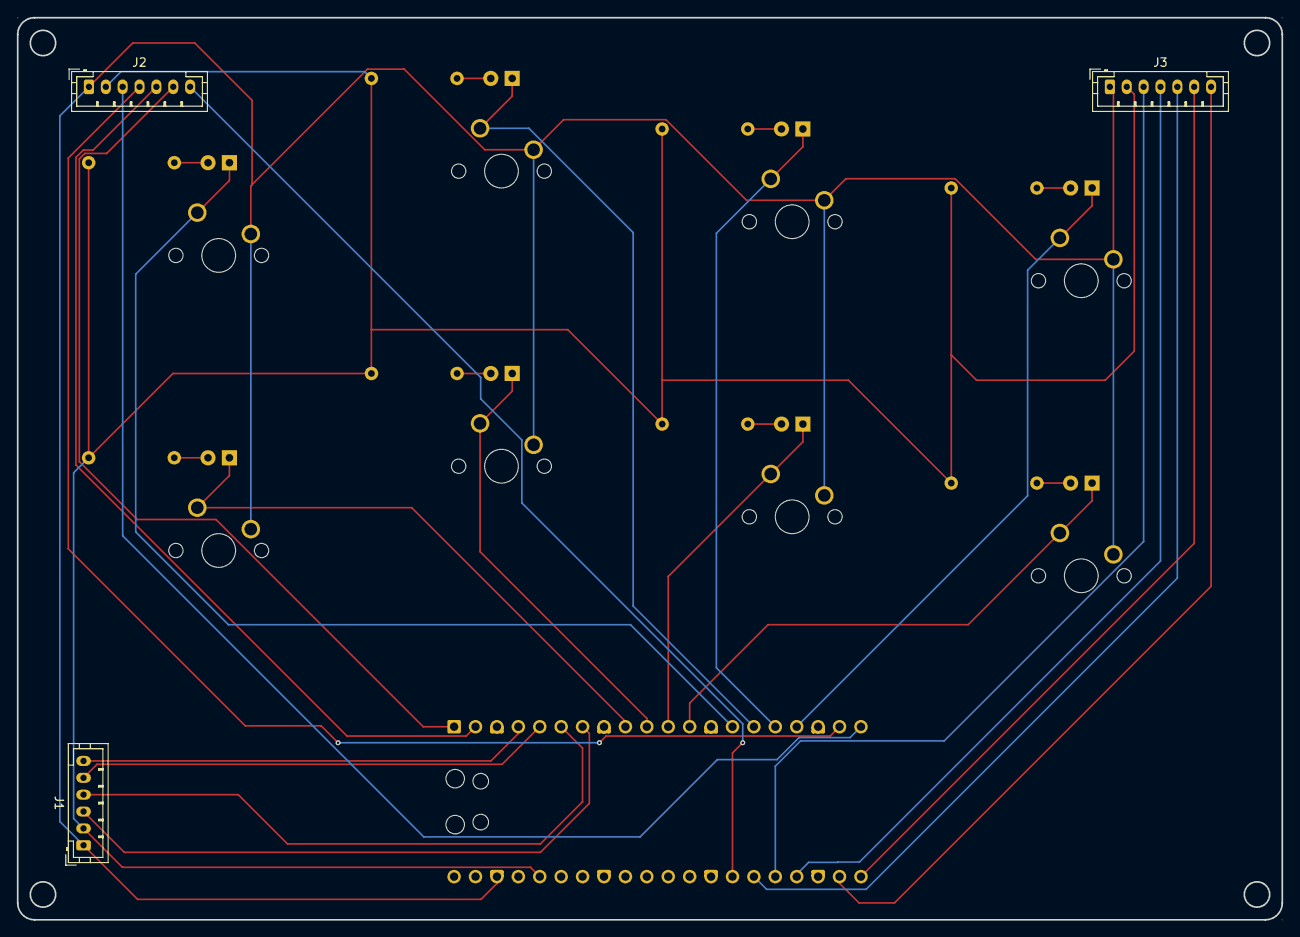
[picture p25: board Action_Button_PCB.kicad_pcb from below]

Board: 2 copper layers, 150.0 x 107.0 mm, 28 parts (3 on the bottom side), 32 nets.

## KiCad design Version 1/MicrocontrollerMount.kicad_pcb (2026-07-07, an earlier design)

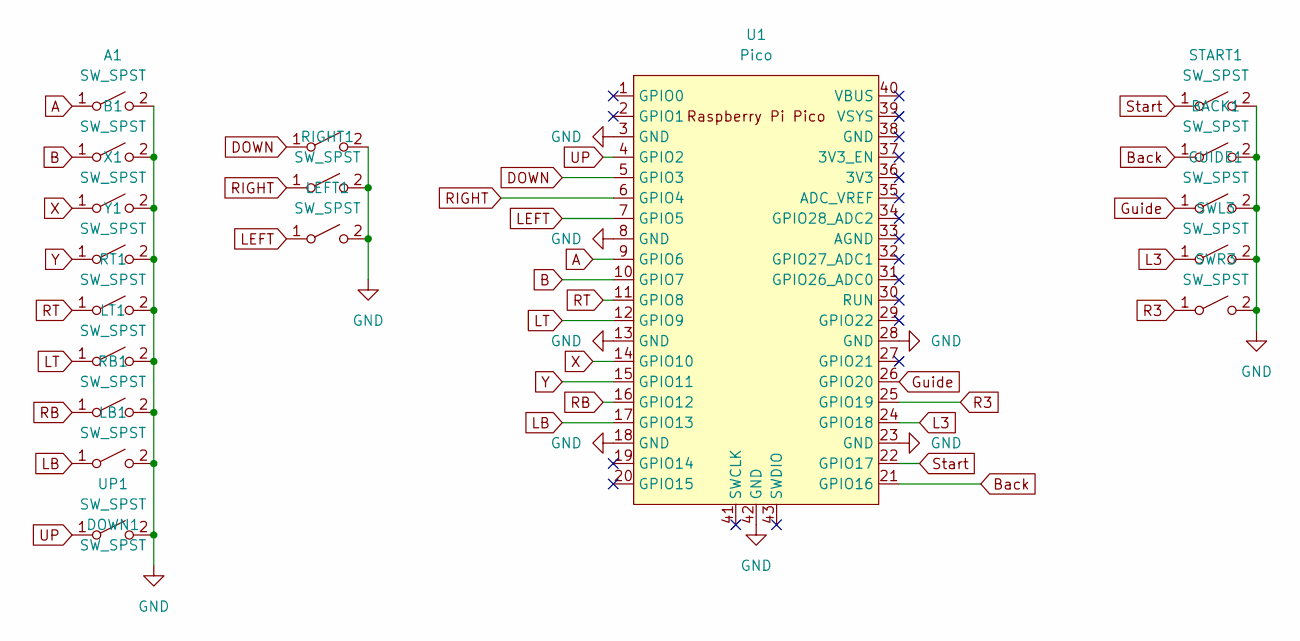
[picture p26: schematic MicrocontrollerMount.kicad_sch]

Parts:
A1: SW_SPST; SW_Cherry_MX_1.00u_PCB
B1: SW_SPST; SW_Cherry_MX_1.00u_PCB
BACK1: SW_SPST; SW_Cherry_MX_1.00u_PCB
DOWN1: SW_SPST; SW_Cherry_MX_1.00u_PCB
GUIDE1: SW_SPST; SW_Cherry_MX_1.00u_PCB
LB1: SW_SPST; SW_Cherry_MX_1.00u_PCB
LEFT1: SW_SPST; SW_Cherry_MX_1.00u_PCB
LT1: SW_SPST; SW_Cherry_MX_1.00u_PCB
RB1: SW_SPST; SW_Cherry_MX_1.00u_PCB
RIGHT1: SW_SPST; SW_Cherry_MX_1.00u_PCB
RT1: SW_SPST; SW_Cherry_MX_1.00u_PCB
START1: SW_SPST; SW_Cherry_MX_1.00u_PCB
SWL3: SW_SPST; SW_Cherry_MX_1.00u_PCB
SWR3: SW_SPST; SW_Cherry_MX_1.00u_PCB
U1: Pico; RPi_Pico_SMD_TH
UP1: SW_SPST; SW_Cherry_MX_1.00u_PCB
X1: SW_SPST; SW_Cherry_MX_1.00u_PCB
Y1: SW_SPST; SW_Cherry_MX_1.00u_PCB

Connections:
A: A1.1 (A), U1.9 (GPIO6)
B: B1.1 (A), U1.10 (GPIO7)
Back: BACK1.1 (A), U1.21 (GPIO16)
DOWN: DOWN1.1 (A), U1.5 (GPIO3)
GND: A1.2 (B), B1.2 (B), BACK1.2 (B), DOWN1.2 (B), GUIDE1.2 (B), LB1.2 (B), LEFT1.2 (B), LT1.2 (B), RB1.2 (B), RIGHT1.2 (B), RT1.2 (B), START1.2 (B), SWL3.2 (B), SWR3.2 (B), U1.3 (GND), U1.8 (GND), U1.13 (GND), U1.18 (GND), U1.23 (GND), U1.28 (GND), U1.42 (GND), UP1.2 (B), X1.2 (B), Y1.2 (B)
Guide: GUIDE1.1 (A), U1.26 (GPIO20)
L3: SWL3.1 (A), U1.24 (GPIO18)
LB: LB1.1 (A), U1.17 (GPIO13)
LEFT: LEFT1.1 (A), U1.7 (GPIO5)
LT: LT1.1 (A), U1.12 (GPIO9)
R3: SWR3.1 (A), U1.25 (GPIO19)
RB: RB1.1 (A), U1.16 (GPIO12)
RIGHT: RIGHT1.1 (A), U1.6 (GPIO4)
RT: RT1.1 (A), U1.11 (GPIO8)
Start: START1.1 (A), U1.22 (GPIO17)
UP: U1.4 (GPIO2), UP1.1 (A)
X: U1.14 (GPIO10), X1.1 (A)
Y: U1.15 (GPIO11), Y1.1 (A)


Board: 2 copper layers, 245.0 x 145.0 mm, 18 parts (0 on the bottom side), 18 nets.

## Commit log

2026-07-06 folder reorganization
    [Southpaw_Split_PCB.kicad_pcb, Southpaw_Split_PCB.kicad_sch]
2026-07-07 hierarchical structure adapted to be flat, also added spec document
    [Action_Button_PCB.kicad_pcb, Action_Button_PCB.kicad_sch, Administrative_Button_PCB.kicad_pcb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]
2026-07-07 rework for schematic structure to accomodate new pico symbol and jst connectors
    [24mm button.stl, 30mm button.stl, Action_Button_PCB.kicad_pcb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]
2026-07-09 created footprints for all lockout and oled display
    [Action_Button_PCB.kicad_sch, Administrative_Button_PCB.kicad_pcb, Administrative_Button_PCB.kicad_sch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]
2026-07-20 general part layout
    [Action_Button_PCB.kicad_pcb, Action_Button_PCB.kicad_sch, Administrative_Button_PCB.kicad_pcb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]
2026-07-23 added sketch reference folder, these will be used to have an exact outline of where parts on the pcb will be since kicad sketching tools aren't great
    [Action_Button_PCB_Reference.SLDPRT]
2026-07-27 First attempt to use solidworks sketches to align parts in kicad
    [Action_Button_PCB.kicad_pcb, Action_Button_PCB.kicad_sch, Action_Button_PCB_Edge_Cuts_Reference.DXF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]
2026-08-10 finished movement pcb, need to make some small adjustments to action pcb
    [Action_Button_PCB.kicad_pcb, Action_Button_PCB_Reference.SLDPRT, Movement_Button_PCB.kicad_pcb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]
2026-08-19 Finalized design and uploaded gerbers to JLCpcb, waiting for boards to come in
    [Action_Button_PCB-B_Cu.gbl, Action_Button_PCB-B_Cu.gbr, Action_Button_PCB-B_Mask.gbr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]
